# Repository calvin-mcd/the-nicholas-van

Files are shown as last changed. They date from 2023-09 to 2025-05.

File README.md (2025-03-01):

# The Nicholas Van
 
The Nicholas Van is an EC (topre) pcb for trashman's [v4n4g0n](https://trashman.wiki/keyboards/v4n4g0n) keyboard. The pcb supports a both the 625U spacebar, and the split 275U, 225U spacebars. But each need their own respective plate. 
Some plate files can be found in the Production folder. Check the plate & hardware section beelow for what you will need. 
The pcb comes with a usb port by default, but supports a Daughterboard connector (either jst or pico). It also supports another 5pin Jst connector for the Rotary Encoder board from the Embrace.

***VERSIONS***:
In the production folder you will find both the prototype production files and the revision files (as well as various plate files). Please be aware of their differences and what aspects have not been confirmed to work yet when ordering pcbs.
- The prototype was sporting a STM32F401 MCU and its rgb could not be made to work. This could have been a firmware issue, but hardware issues could not be ruled out. Otherwise the pcb was fully working
- The revision is using a STM32F072 MCU and simplified components and an attempt to fix the rgb hardware. The revision has not been prototyped yet and firmware needs to be adapted to its rgb hardware setup.

## Layout

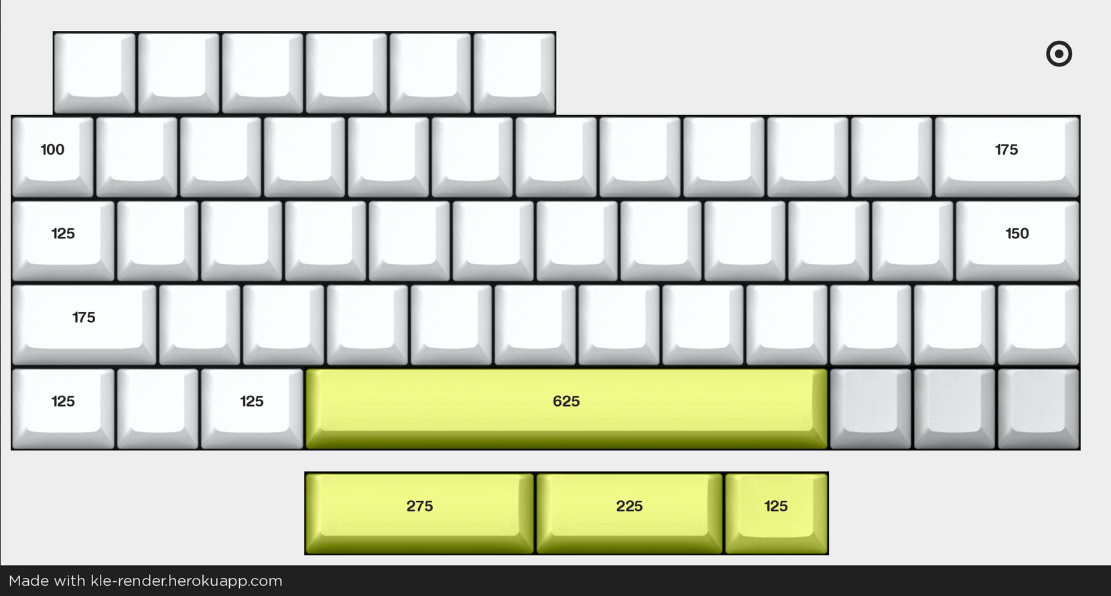
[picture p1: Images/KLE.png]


[Link](http://www.keyboard-layout-editor.com/#/gists/a55206434a137895f2c476b4f5ef8018)

## Images

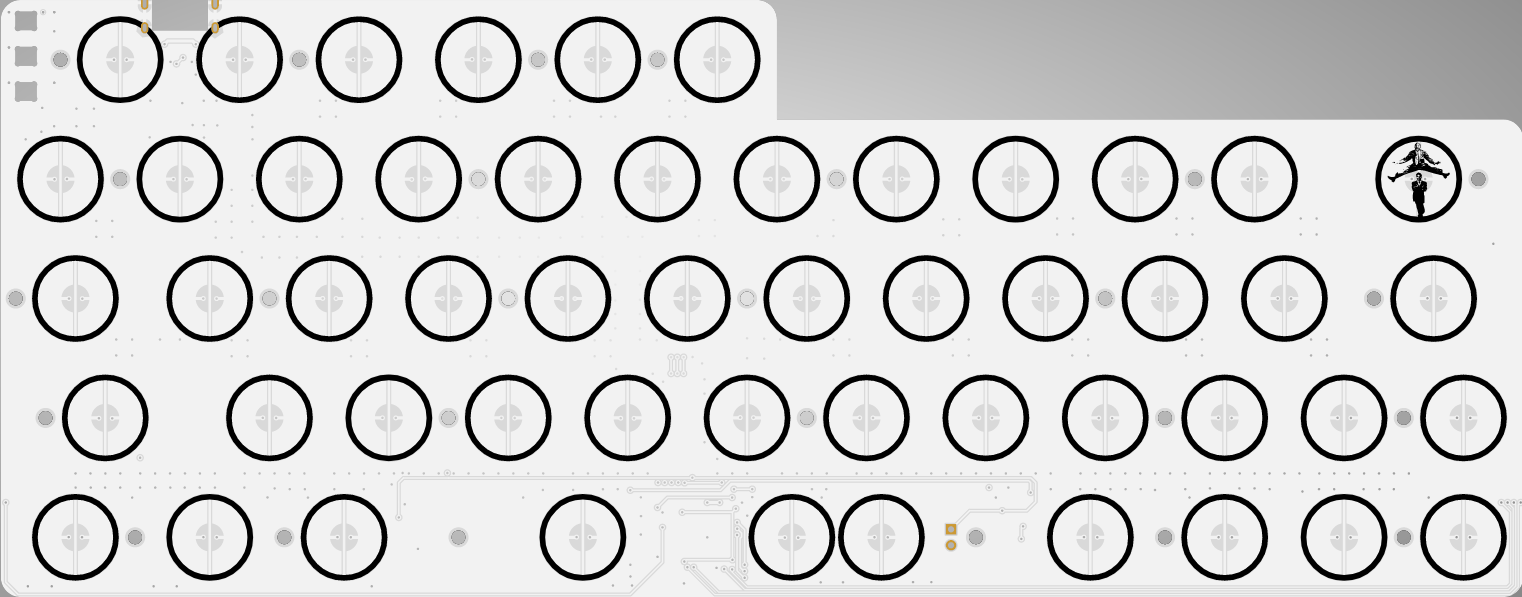
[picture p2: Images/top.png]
  
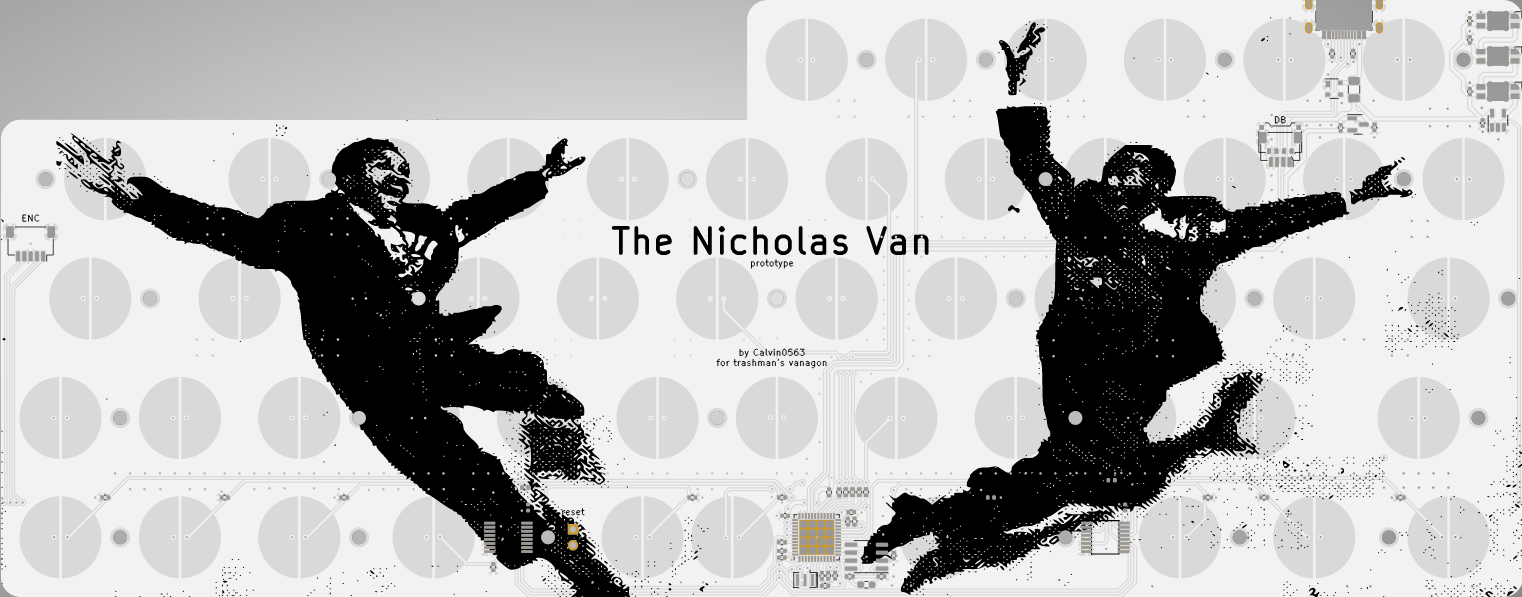
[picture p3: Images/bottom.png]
  

## Firmware

The basic EC firmware is ready to go and the source code is provided for tweaking any settings.

## Plates & Hardware

Plate files are available for OEM (original and deskey housings), for each respective bottom row choice, and for the original plate, Hull and Embrace cases.

Furthermore, you will need 26x 10mm M2 screws and M2 nuts to assemble the pcb. O-rings might help aligning the pcb and usb port in some cases, but is not required.

## Disclaimer

Please note that this project is a work in progress with no guarantees of a working outcome. No-one involved in this project is responsible for any usage issues that may arise. Order at your own risk. Support will not be provided but pull requests will be reviewed and possibly accepted.

## License

Shield: 

This work is licensed under a  
[Creative Commons Attribution-NonCommercial-ShareAlike 4.0 International License](http://creativecommons.org/licenses/by-nc-sa/4.0/).



## Credits

big thanks to M4NU for repeatedly begging for a topre vanagon pcb! ;)

Otherwise, many thanks for feedback, help, references go to Sporkus, Cipulot\#8455 & matthewdias\#2671.

Any questions, contact Calvin0563 on Discord.

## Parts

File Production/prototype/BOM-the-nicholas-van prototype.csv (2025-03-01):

Comment | Designator | Footprint | LCSC | Quantity
1k | R19 | R_0402_1005Metric | C11702 | 1
STM32F401CBUx | U1 | QFN-48-1EP_7x7mm_P0.5mm_EP5.6x5.6mm | C118825 | 1
74AHCT1G125 | U3 | SOT-23-5 | C12494 | 1
OPA350 | U5 | SOIC-8_3.9x4.9mm_P1.27mm | C13388 | 1
Conn_01x05 | J4 | JST_SH_SM05B-SRSS-TB_1x05-1MP_P1.00mm_Horizontal | C136657 | 1
220p | C12 | C_0402_1005Metric | C1530 | 1
JST SH | J1 | JST_SH_SM04B-SRSS-TB_1x04-1MP_P1.00mm_Horizontal | C160404 | 1
4.7u | C1 | C_0402_1005Metric | C23733 | 1
100 | R2,R3,R4,R5,R6 | R_0402_1005Metric | C25076 | 5
100k | R1,R10,R15,R16,R17,R18,R20,R21,R22,R23,R24,R25,R26,R7 | R_0402_1005Metric | C25741 | 14
10k | R11,R8,R9 | R_0402_1005Metric | C25744 | 3
5.1k | R12,R13 | R_0402_1005Metric | C25905 | 2
PRTR5V0U2X | D1 | SOT-143 | C2827688 | 1
USB_C sink board 1.3mm | J3 | USB4510031A | C3019717 | 1
100n | C11,C13,C14,C15,C16,C17,C18,C2,C3,C4,C5,C6 | C_0402_1005Metric | C307331 | 12
SK6812MINI-E | LED1,LED2,LED3 | SK6812-MINI-E | C5149201 | 3
1u | C7,C8,C9 | C_0402_1005Metric | C52923 | 3
XC6206PxxxMR | U2 | SOT-23 | C5446 | 1
74HC4051 | U4,U6 | TSSOP16 | C5645 | 2
500mA | F_USBC1 | Fuse_1206_3216Metric | C70076 | 1
8 MHz | Y1 | Resonator_SMD_Murata_CSTxExxV-3Pin_3.0x1.1mm | C907975 | 1
Pico EZmate | J2 | Molex_Pico-EZmate_78171-0004_1x04-1MP_P1.20mm_Vertical |  | 1

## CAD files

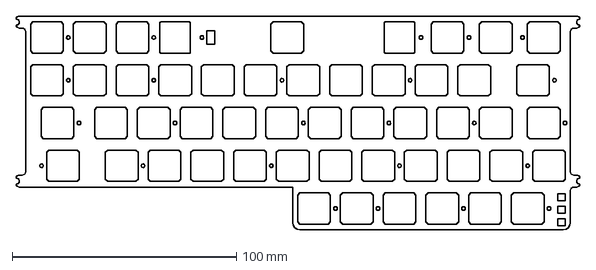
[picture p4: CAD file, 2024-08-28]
Production/plate files/nicholas van full bar threaded.dxf
251.3 x 95.3 mm

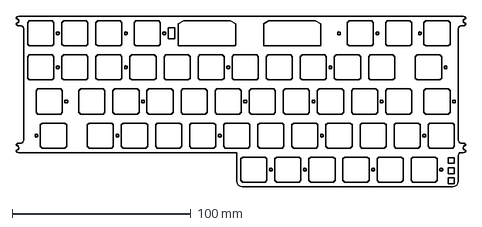
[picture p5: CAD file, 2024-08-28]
Production/plate files/nicholas split threaded.dxf
251.3 x 95.3 mm

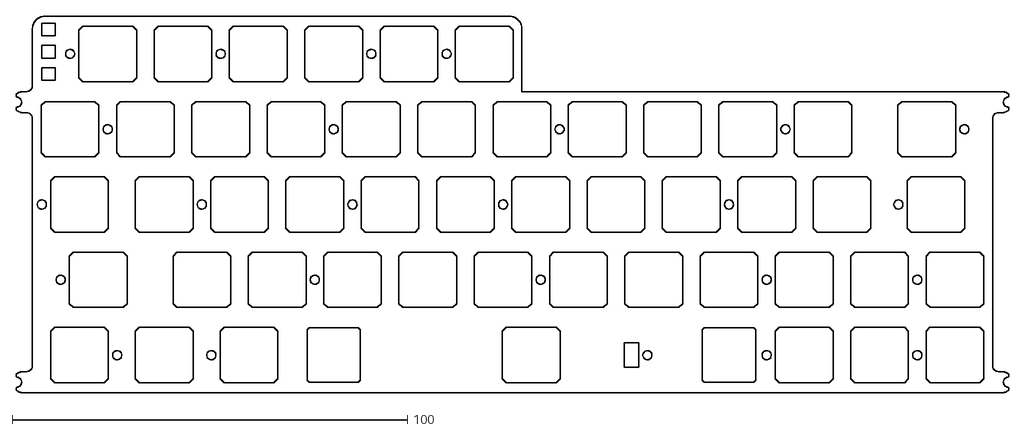
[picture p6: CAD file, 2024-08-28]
Project/Plates/Production/Hull OEM 625u-F_Cu.dxf
251.2 x 95.2

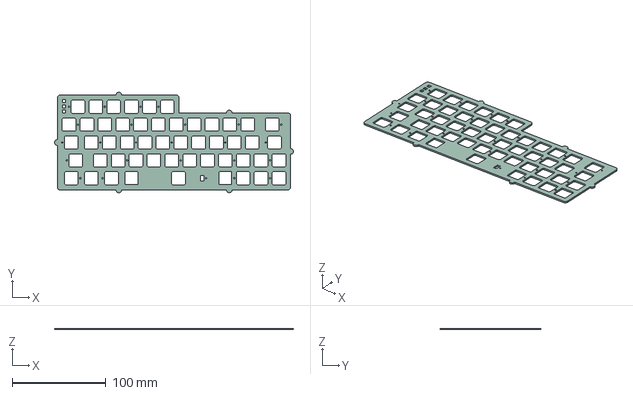
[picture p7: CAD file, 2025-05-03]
Project/Plates/Vanagon OEM 625u.step
254.9 x 107.3 x 1.59 mm

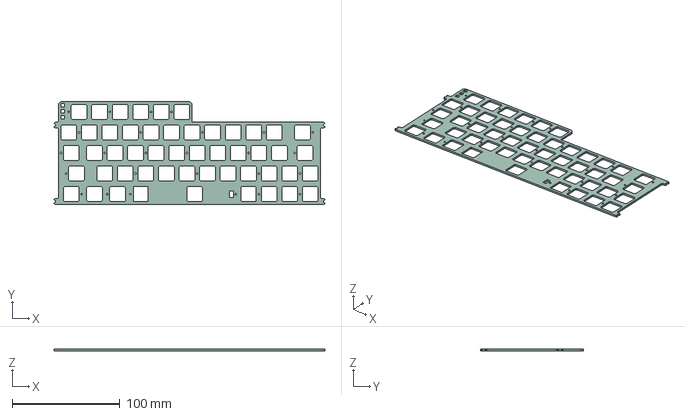
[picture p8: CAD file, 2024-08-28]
Project/Plates/V1 Hull 625u threaded.step
251.2 x 95.2 x 1.59 mm

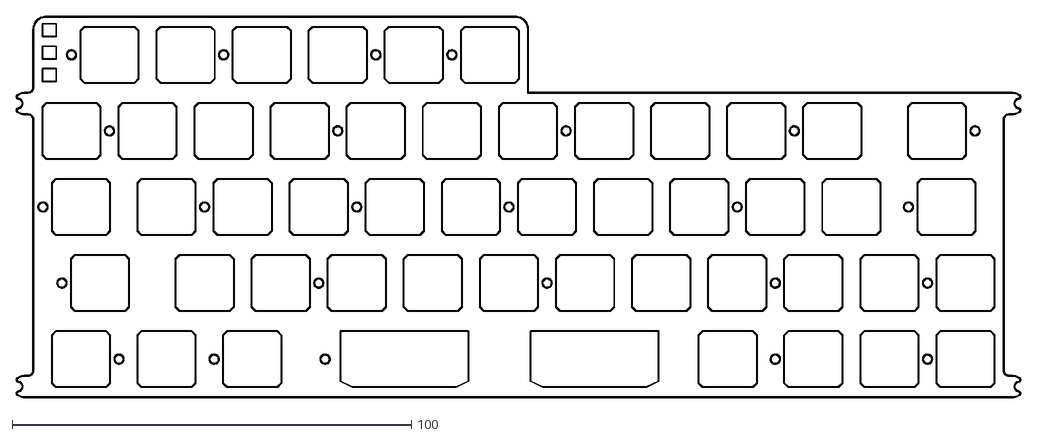
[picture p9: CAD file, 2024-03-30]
Project/Plates/Production/Hull OEM 275u 225u-Edge_Cuts.dxf
251.4 x 95.4

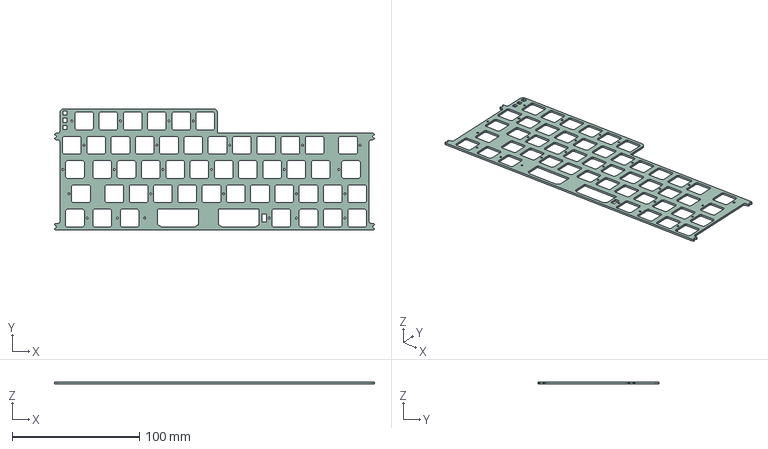
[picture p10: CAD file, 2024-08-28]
Project/Plates/V1 Hull 275u 225u threaded.step
251.2 x 95.2 x 1.59 mm

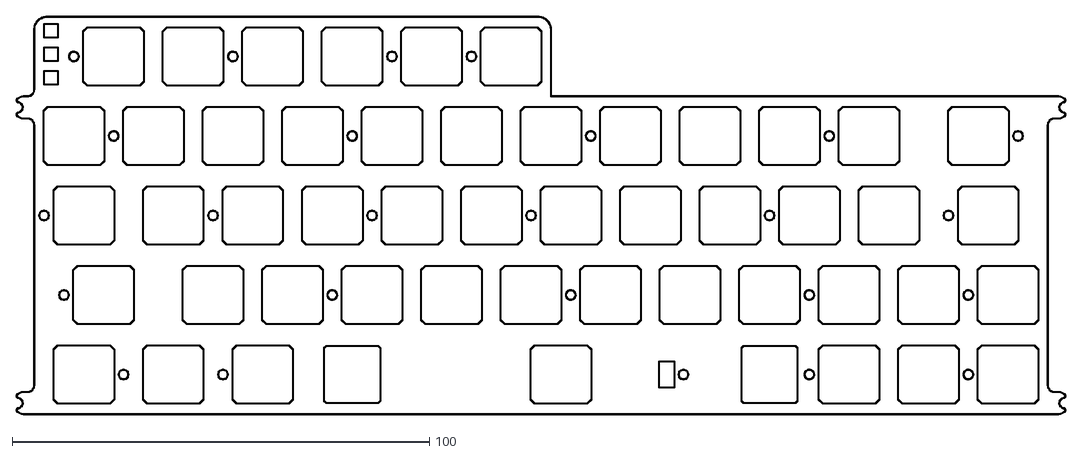
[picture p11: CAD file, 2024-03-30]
Project/Plates/Production/Hull OEM 625u-Edge_Cuts.dxf
251.4 x 95.4

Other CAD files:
Project/Plates/Production/Hull OEM 625u-B_Mask.dxf
Project/Plates/Production/Hull OEM 625u-B_Paste.dxf
Project/Plates/Production/Hull OEM 625u-B_Silkscreen.dxf
Project/Plates/Production/Hull OEM 625u-F_Mask.dxf
Project/Plates/Production/Hull OEM 625u-F_Paste.dxf
Project/Plates/Production/Hull OEM 625u-F_Silkscreen.dxf

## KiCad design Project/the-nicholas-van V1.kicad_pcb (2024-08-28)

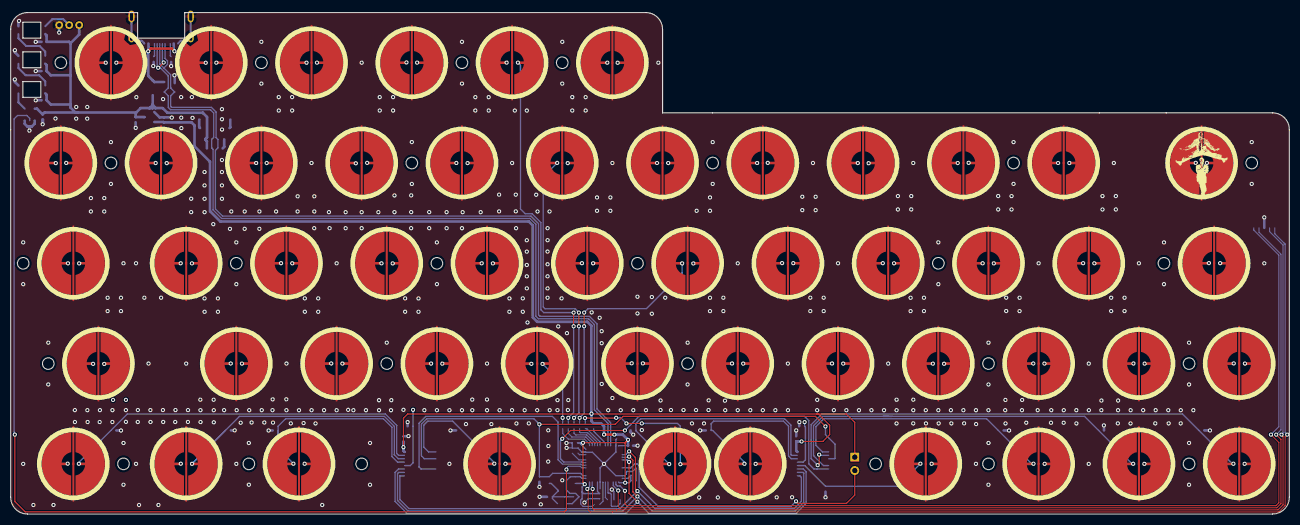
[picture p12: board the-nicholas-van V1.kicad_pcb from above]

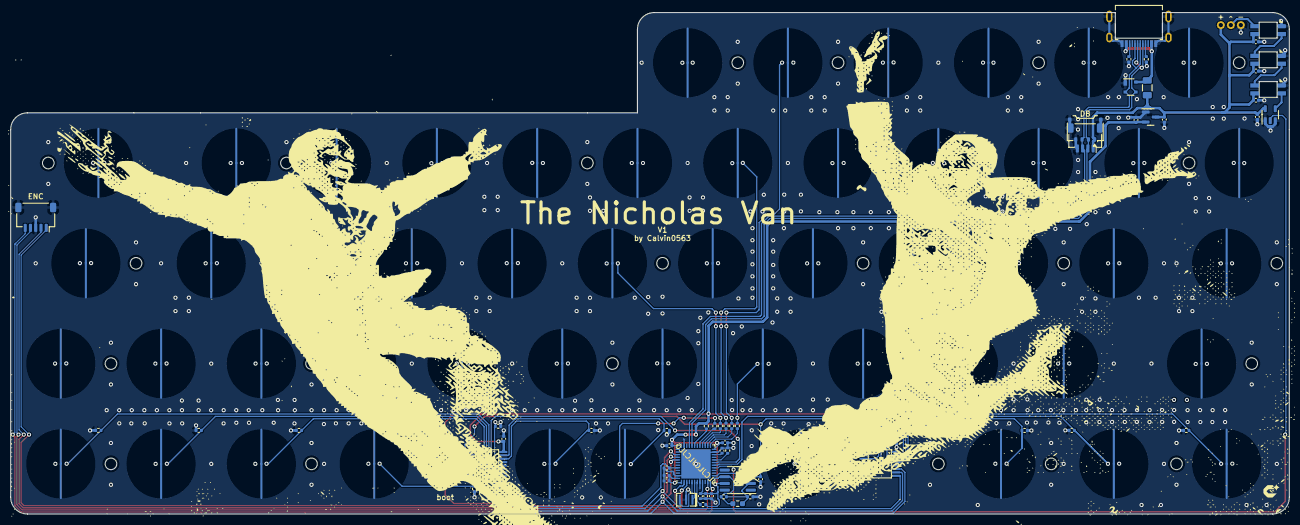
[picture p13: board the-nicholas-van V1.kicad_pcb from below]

Board: 4 copper layers, 242.9 x 95.2 mm, 139 parts (61 on the bottom side), 54 nets.

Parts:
C1: 4.7u; C_0402_1005Metric
C2, C3, C4, C5, C6, C11, C13, C14, C15, C16, C17, C18: 100n; C_0402_1005Metric
C7, C8, C9: 1u; C_0402_1005Metric
C12: 220p; C_0402_1005Metric
D1: PRTR5V0U2X; SOT-143
F_USBC1: 500mA; Fuse_1206_3216Metric
H1, H2, H3, H4, H5, H6, H7, H8, H9, H10, H11, H12, H13, H14, H15, H16, H17, H18, H19, H20, H21, H22, H23, H24, H25, H26: MountingHole; HOLE_M2
J1: JST SH; JST_SH_SM04B-SRSS-TB_1x04-1MP_P1.00mm_Horizontal
J2: Pico EZmate; Molex_Pico-EZmate_78171-0004_1x04-1MP_P1.20mm_Vertical
J3: USB_C sink board 1.3mm; USB4510031A
J4: Conn_01x05; JST_SH_SM05B-SRSS-TB_1x05-1MP_P1.00mm_Horizontal
J5: ARGB; PinHeader_1x03_P1.27mm_Vertical
JP1: Ext_Res; R_0603_1608Metric_Pad0.98x0.95mm_HandSolder
LED1, LED2, LED3: SK6812MINI-E; SK6812-MINI-E
R1, R7, R10, R15, R16, R17, R18, R20, R21, R22, R23, R24, R25, R26: 100k; R_0402_1005Metric
R2, R3, R4, R5, R6: 100; R_0402_1005Metric
R8, R9, R11: 10k; R_0402_1005Metric
R12, R13: 5.1k; R_0402_1005Metric
R19: 1k; R_0402_1005Metric
SW1: BOOT0; PinHeader_1x02_P2.54mm_Vertical
SW_EC1, SW_EC2, SW_EC3, SW_EC4, SW_EC5, SW_EC6, SW_EC7, SW_EC8, SW_EC9, SW_EC10, SW_EC11, SW_EC12, SW_EC13, SW_EC14, SW_EC15, SW_EC16, SW_EC17, SW_EC18, SW_EC19, SW_EC20, SW_EC21, SW_EC22, SW_EC23, SW_EC24, SW_EC25, SW_EC26, SW_EC27, SW_EC28, SW_EC29, SW_EC30, SW_EC31, SW_EC32, SW_EC33, SW_EC34, SW_EC35, SW_EC36, SW_EC37, SW_EC38, SW_EC39, SW_EC40, SW_EC41, SW_EC42, SW_EC43, SW_EC44, SW_EC45, SW_EC46, SW_EC47, SW_EC48, SW_EC49, SW_EC50, SW_EC51, SW_EC54: Topre; ecs_pad_1U_no_ring
U1: STM32F401CBUx; QFN-48-1EP_7x7mm_P0.5mm_EP5.6x5.6mm
U2: XC6206PxxxMR; SOT-23
U3: 74AHCT1G125; SOT-23-5
U4, U6: 74HC4051; TSSOP16
U5: OPA350; SOIC-8_3.9x4.9mm_P1.27mm
Y1: 8 MHz; Resonator_SMD_Murata_CSTxExxV-3Pin_3.0x1.1mm

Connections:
+5V: C8.1, C15.1, C16.1, C17.1, C18.1, F_USBC1.2, J1.1, J2.1, J5.3, LED1.1 (VDD), LED2.1 (VDD), LED3.1 (VDD), U2.3 (VI), U3.5 (+5V)
ADC: JP1.1 (A), R7.2, U1.13 (PA3), U5.6 (OUT)
AMUX_SEL_0: U1.41 (PB5), U4.11 (S0), U6.11 (S0)
AMUX_SEL_1: U1.40 (PB4), U4.10 (S1), U6.10 (S1)
AMUX_SEL_2: U1.39 (PB3), U4.9 (S2), U6.9 (S2)
APLEX_EN_PIN_0: U1.18 (PB0), U4.6 (~E)
APLEX_EN_PIN_1: U1.19 (PB1), U6.6 (~E)
APLEX_OUT_PIN_0: C12.2, U1.14 (PA4), U4.3 (A), U5.3 (IN+), U6.3 (A)
ARGB: J5.2, LED3.2 (DOUT)
ARGB_3V3: U1.17 (PA7), U3.2
ARGB_5V: LED1.4 (DIN), U3.4
BOOT0: R11.1, SW1.2 (B), U1.44 (BOOT0)
BOOT1: R9.2, U1.20 (PB2)
COL0: R16.1, SW_EC1.2, SW_EC7.2, SW_EC19.2, SW_EC31.2, SW_EC43.2, U4.15 (A2)
COL1: R15.1, SW_EC2.2, SW_EC8.2, SW_EC20.2, SW_EC32.2, SW_EC44.2, U4.14 (A1)
COL2: R10.1, SW_EC3.2, SW_EC9.2, SW_EC21.2, SW_EC33.2, SW_EC45.2, U4.13 (A0)
COL3: R17.1, SW_EC4.2, SW_EC10.2, SW_EC22.2, SW_EC34.2, U4.12 (A3)
COL4: R18.1, SW_EC5.2, SW_EC11.2, SW_EC23.2, SW_EC35.2, SW_EC46.2, U4.1 (A4)
COL5: R22.1, SW_EC6.2, SW_EC12.2, SW_EC24.2, SW_EC36.2, SW_EC47.2, U6.15 (A2)
COL6: R21.1, SW_EC13.2, SW_EC25.2, SW_EC37.2, SW_EC48.2, U6.14 (A1)
COL7: R20.1, SW_EC14.2, SW_EC26.2, SW_EC38.2, U6.13 (A0)
COL8: R23.1, SW_EC15.2, SW_EC27.2, SW_EC39.2, SW_EC49.2, U6.12 (A3)
COL9: R24.1, SW_EC16.2, SW_EC28.2, SW_EC40.2, SW_EC50.2, U6.1 (A4)
COL10: R25.1, SW_EC17.2, SW_EC29.2, SW_EC41.2, SW_EC51.2, U6.5 (A5)
COL11: R26.1, SW_EC18.2, SW_EC30.2, SW_EC42.2, SW_EC54.2, U6.2 (A6)
D+: D1.2 (I/O1), J1.3, J2.3, J3.A6 (D+), J3.B6 (D+), U1.33 (PA12)
D-: D1.3 (I/O2), J1.2, J2.2, J3.A7 (D-), J3.B7 (D-), U1.32 (PA11)
ENC1: J4.2, U1.3 (PC14)
ENC2: J4.4, U1.11 (PA1)
GND: C1.2, C2.2, C3.2, C4.2, C5.2, C6.2, C7.2, C8.2, C9.2, C11.2, C12.1, C13.2, C14.2, C15.2, C16.2, C17.2, C18.2, D1.1 (GND), J1.4, J1.MP (MountPin), J2.4, J2.MP (MountPin), J3.A1 (GND), J3.A12 (GND), J3.S1 (SHIELD), J4.3, J4.MP (MountPin), J5.1, LED1.3 (VSS), LED2.3 (VSS), LED3.3 (VSS), R9.1, R10.2, R11.2, R12.2, R13.2, R15.2, R16.2, R17.2, R18.2, R19.2, R20.2, R21.2, R22.2, R23.2, R24.2, R25.2, R26.2, SW_EC1.3, SW_EC2.3, SW_EC3.3, SW_EC4.3, SW_EC5.3, SW_EC6.3, SW_EC7.3, SW_EC8.3, SW_EC9.3, SW_EC10.3, SW_EC11.3, SW_EC12.3, SW_EC13.3, SW_EC14.3, SW_EC15.3, SW_EC16.3, SW_EC17.3, SW_EC18.3, SW_EC19.3, SW_EC20.3, SW_EC21.3, SW_EC22.3, SW_EC23.3, SW_EC24.3, SW_EC25.3, SW_EC26.3, SW_EC27.3, SW_EC28.3, SW_EC29.3, SW_EC30.3, SW_EC31.3, SW_EC32.3, SW_EC33.3, SW_EC34.3, SW_EC35.3, SW_EC36.3, SW_EC37.3, SW_EC38.3, SW_EC39.3, SW_EC40.3, SW_EC41.3, SW_EC42.3, SW_EC43.3, SW_EC44.3, SW_EC45.3, SW_EC46.3, SW_EC47.3, SW_EC48.3, SW_EC49.3, SW_EC50.3, SW_EC51.3, SW_EC54.3, U1.8 (VSSA), U1.23 (VSS), U1.35 (VSS), U1.47 (VSS), U1.49 (VSS), U2.1 (GND), U3.1, U3.3 (GND), U4.2 (A6), U4.4 (A7), U4.5 (A5), U4.7 (VEE), U4.8 (GND), U5.4 (V-), U6.4 (A7), U6.7 (VEE), U6.8 (GND), Y1.2
NRST: R8.2, U1.7 (NRST)
unnamed: J3.A5 (CC1), R12.1
unnamed: J3.B5 (CC2), R13.1
unnamed: JP1.2 (B), R7.1, R19.1, U5.2 (IN-)
unnamed: LED1.2 (DOUT), LED2.4 (DIN)
unnamed: LED2.2 (DOUT), LED3.4 (DIN)
unnamed: R6.2, U1.29 (PA8)
unnamed: R1.1, U1.31 (PA10)
unnamed: R2.2, U1.25 (PB12)
unnamed: R3.2, U1.26 (PB13)
unnamed: R4.2, U1.27 (PB14)
unnamed: R5.2, U1.28 (PB15)
unnamed: C1.1, U1.22 (VCAP1)
ROW0: R3.1, SW_EC1.1, SW_EC2.1, SW_EC3.1, SW_EC4.1, SW_EC5.1, SW_EC6.1
ROW1: R4.1, SW_EC7.1, SW_EC8.1, SW_EC9.1, SW_EC10.1, SW_EC11.1, SW_EC12.1, SW_EC13.1, SW_EC14.1, SW_EC15.1, SW_EC16.1, SW_EC17.1, SW_EC18.1
ROW2: R5.1, SW_EC19.1, SW_EC20.1, SW_EC21.1, SW_EC22.1, SW_EC23.1, SW_EC24.1, SW_EC25.1, SW_EC26.1, SW_EC27.1, SW_EC28.1, SW_EC29.1, SW_EC30.1
ROW3: R2.1, SW_EC31.1, SW_EC32.1, SW_EC33.1, SW_EC34.1, SW_EC35.1, SW_EC36.1, SW_EC37.1, SW_EC38.1, SW_EC39.1, SW_EC40.1, SW_EC41.1, SW_EC42.1
ROW4: R6.1, SW_EC43.1, SW_EC44.1, SW_EC45.1, SW_EC46.1, SW_EC47.1, SW_EC48.1, SW_EC49.1, SW_EC50.1, SW_EC51.1, SW_EC54.1
SW1: J4.1, U1.2 (PC13)
SW2: J4.5, U1.12 (PA2)
VBAT: C2.1, C3.1, C4.1, C5.1, C6.1, C7.1, C9.1, C11.1, C13.1, C14.1, R1.2, R8.1, SW1.1 (A), U1.1 (VBAT), U1.9 (VREF+), U1.24 (VDD), U1.36 (VDD), U1.48 (VDD), U2.2 (VO), U4.16 (VCC), U5.7 (V+), U6.16 (VCC)
VCC: D1.4 (VCC), F_USBC1.1, J3.A4 (VBUS), J3.A9 (VBUS)
XTAL0: U1.5 (PH0), Y1.3
XTAL1: U1.6 (PH1), Y1.1

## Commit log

2023-09-15 project initialised
    [Embrace OEM 275u 225u.kicad_pcb, Embrace OEM 625u.kicad_pcb, Hull OEM 275u 225u.kicad_pcb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]
2023-09-24 created production files
    [BOM-the-nicholas-van.csv, Vanagon OEM 275u 225u.kicad_pcb, Vanagon OEM 625u.kicad_pcb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]
2023-10-01 fresh production files
    [BOM-the-nicholas-van.csv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]
2023-11-17 added rgb breakout
    [the-nicholas-van.kicad_sch]
2023-12-02 rgb symbol/footprint mismatch corrected, fresh gerbers, etc
    [BOM-the-nicholas-van.csv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]
2024-01-31 changed rgb pin for better compatibilty
    [the-nicholas-van.kicad_sch]
2024-02-23 MX support pcb and plate
    [Hull OEM 275u 225u MX.kicad_pcb, Hull OEM 625u MX.kicad_pcb]
2024-03-30 plate revisions
    [Hull 275u 225u MX.kicad_pcb, Hull 275u 225u.kicad_pcb, Hull 625u MX.kicad_pcb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]
2024-08-05 revision V1
    changed bottom row mounting and boot cut for plates
    [Hull 275u 225u MX.kicad_pcb, V1 Hull 275u 225u threaded.kicad_pcb, V1 Hull 625u threaded.kicad_pcb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]
2024-08-11 v1 work
    [the-nicholas-van V1.kicad_pcb]
2024-08-28 revision update
    [BOM-the-nicholas-van V1.csv, BOM-the-nicholas-van.csv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]
2024-11-26 update revision
    [analog v1.kicad_sch, analog.kicad_sch, matrix.kicad_sch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]
2024-12-22 publishing changes
    [BOM-the-nicholas-van V1.csv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]
2025-03-01 update production files
    before release
    [BOM-the-nicholas-van V1.csv, BOM-the-nicholas-van prototype.csv, BOM-the-nicholas-van revision.csv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]
